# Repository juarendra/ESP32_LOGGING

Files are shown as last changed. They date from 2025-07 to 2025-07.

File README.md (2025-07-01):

# ESP32_LOGGING

## Table of Content

* [Product Specsification](#product-specsification)
* [Technical Spesification](#technical-spesification)
* [Applications](#applications)
* [Advantages](#advantages)
* [Priview Hardware](#priview-hardware)
* [Documentation](#documentation)
  * [Pinout Diagram](#pinout-diagram)
  * [Dimension](#dimension)
  * [BOM](#bom)
  * [Schematic](#schematic0)
  * [Example Program](#examples-program)
* [FAQ](#FAQ)

## Preview Hardware
<p align="center">
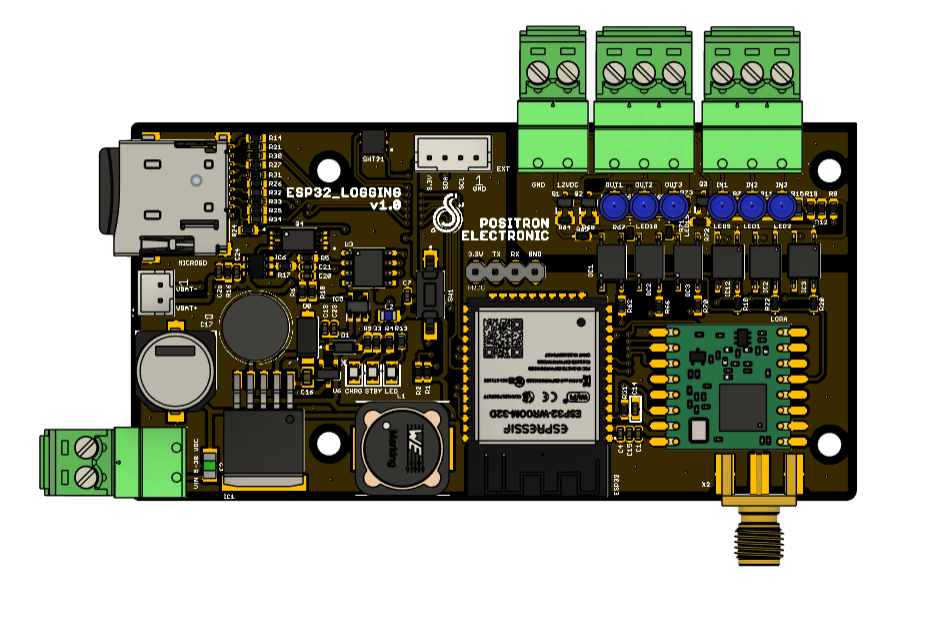
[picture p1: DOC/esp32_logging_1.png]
  
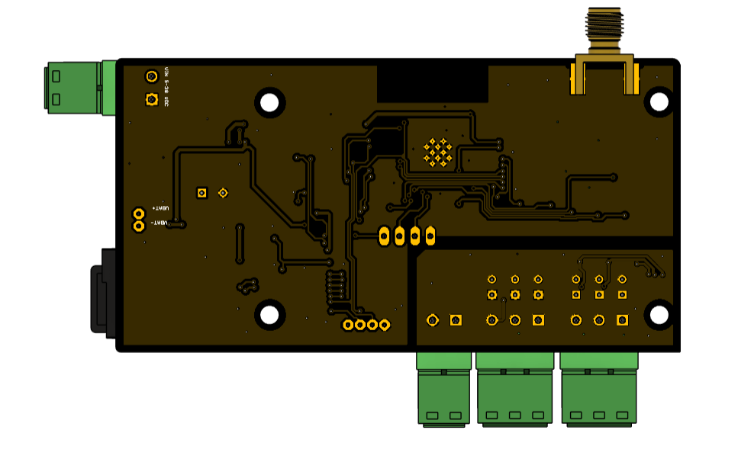
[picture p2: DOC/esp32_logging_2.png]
  
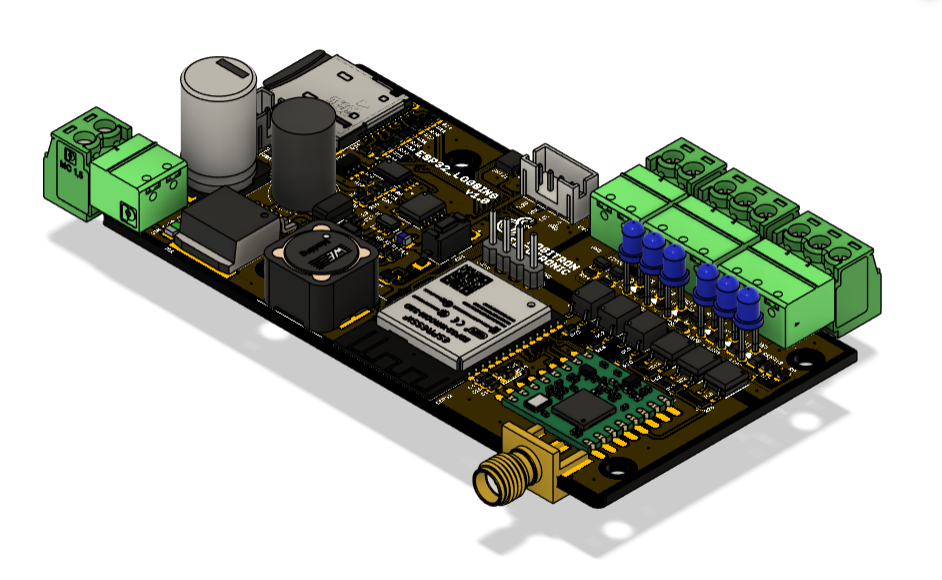
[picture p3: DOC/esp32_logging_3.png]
  
</p>

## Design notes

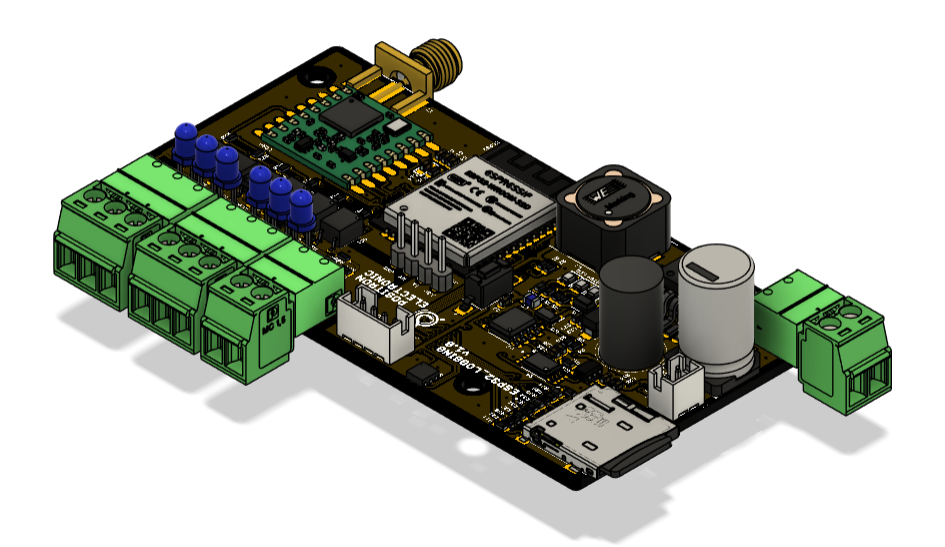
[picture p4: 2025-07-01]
DOC/esp32_logging_4.png

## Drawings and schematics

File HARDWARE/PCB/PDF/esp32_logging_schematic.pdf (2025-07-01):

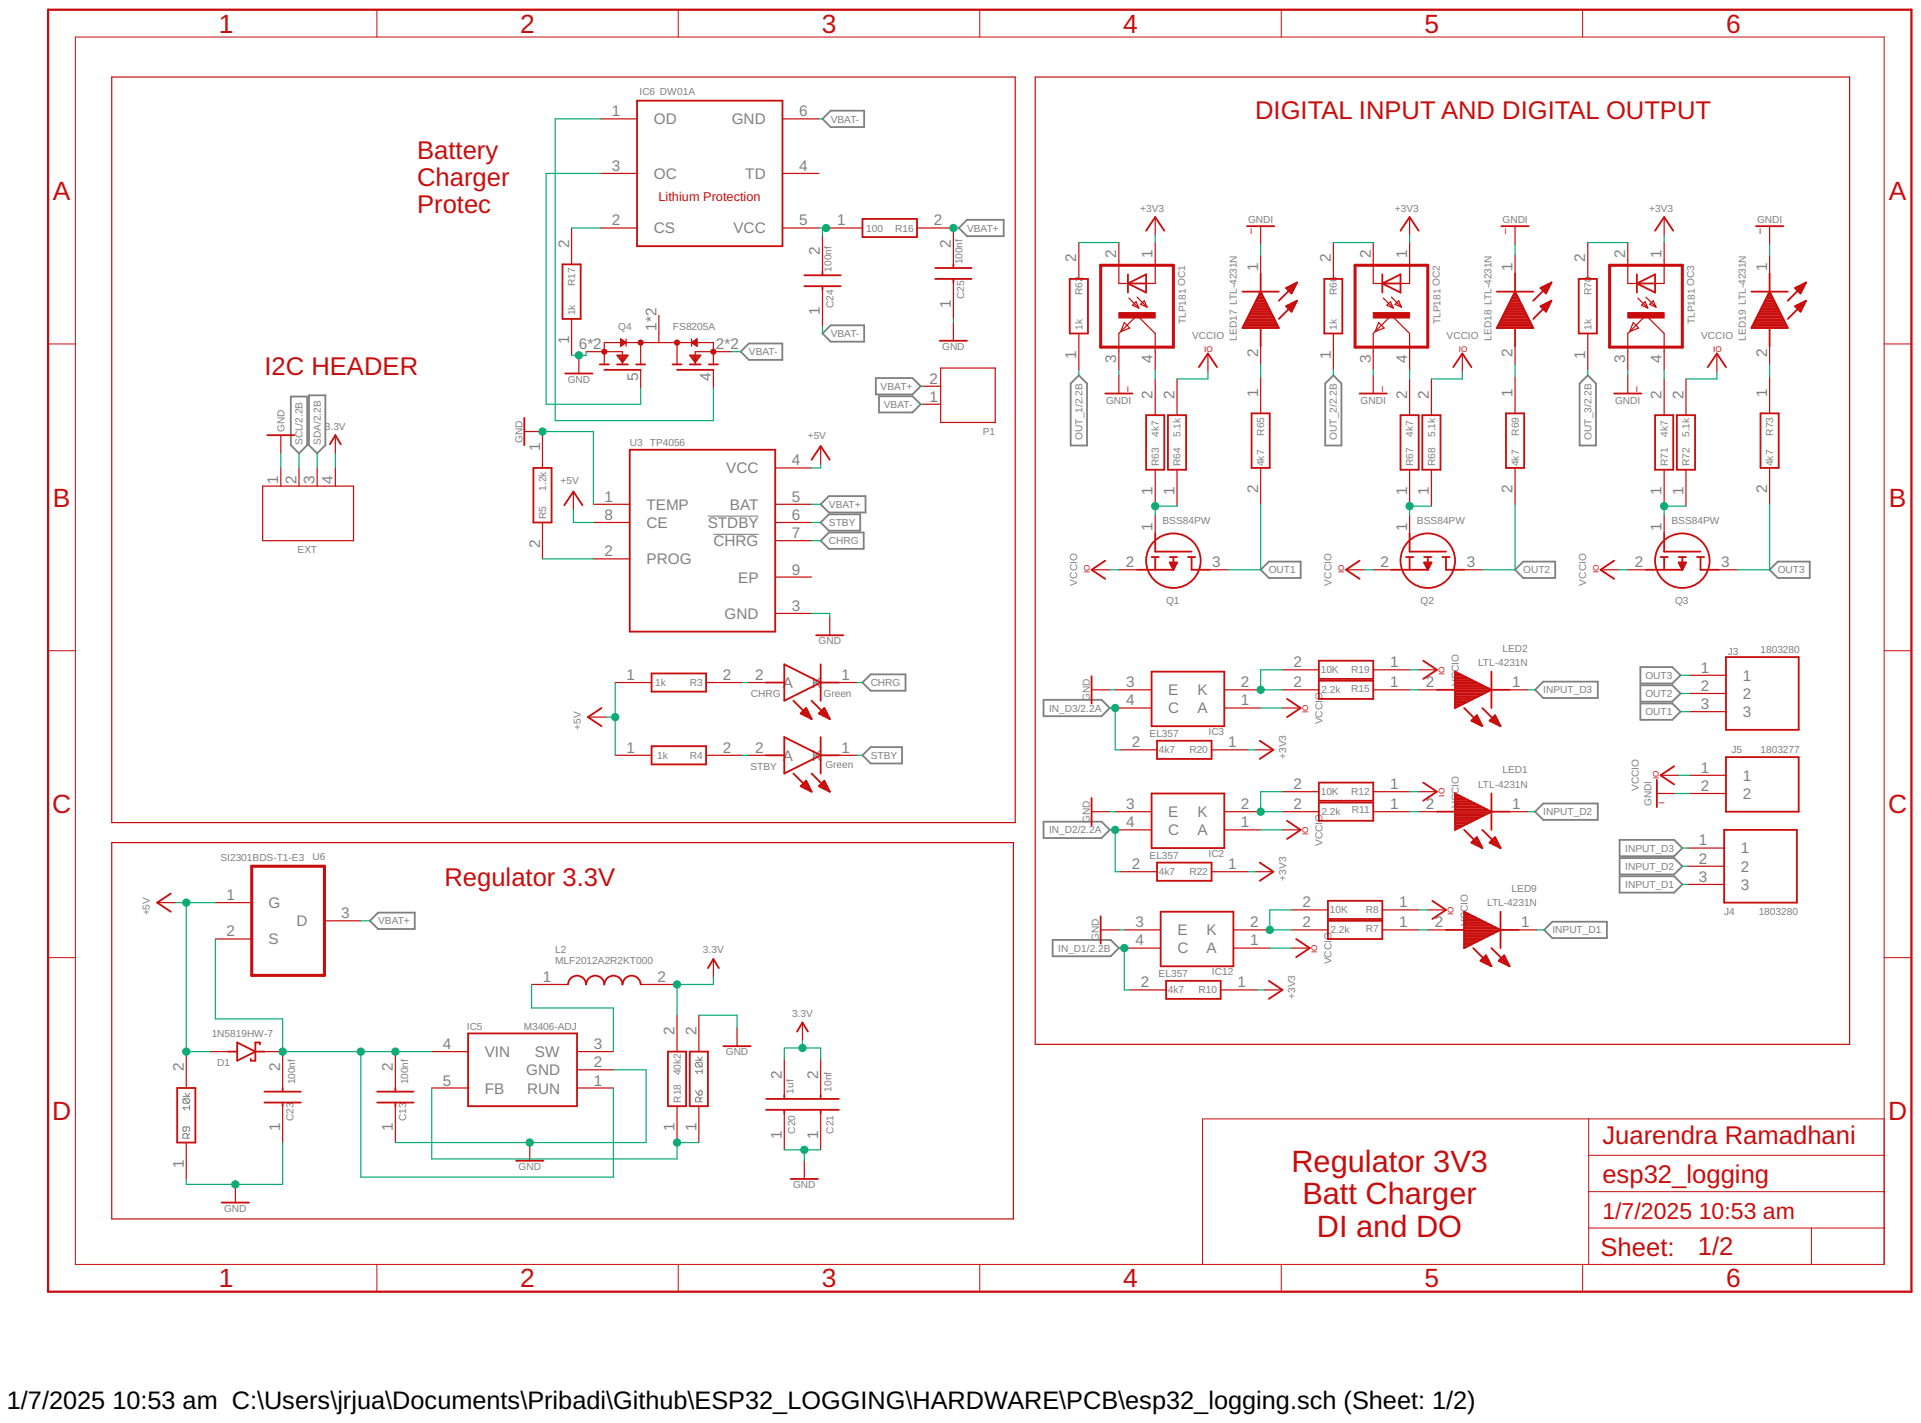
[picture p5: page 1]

DIGITAL INPUT AND DIGITAL OUTPUT

1/7/2025 10:53 am C:\Users\jrjua\Documents\Pribadi\Github\ESP32_LOGGING\HARDWARE\PCB\esp32_logging.sch (Sheet: 1/2)

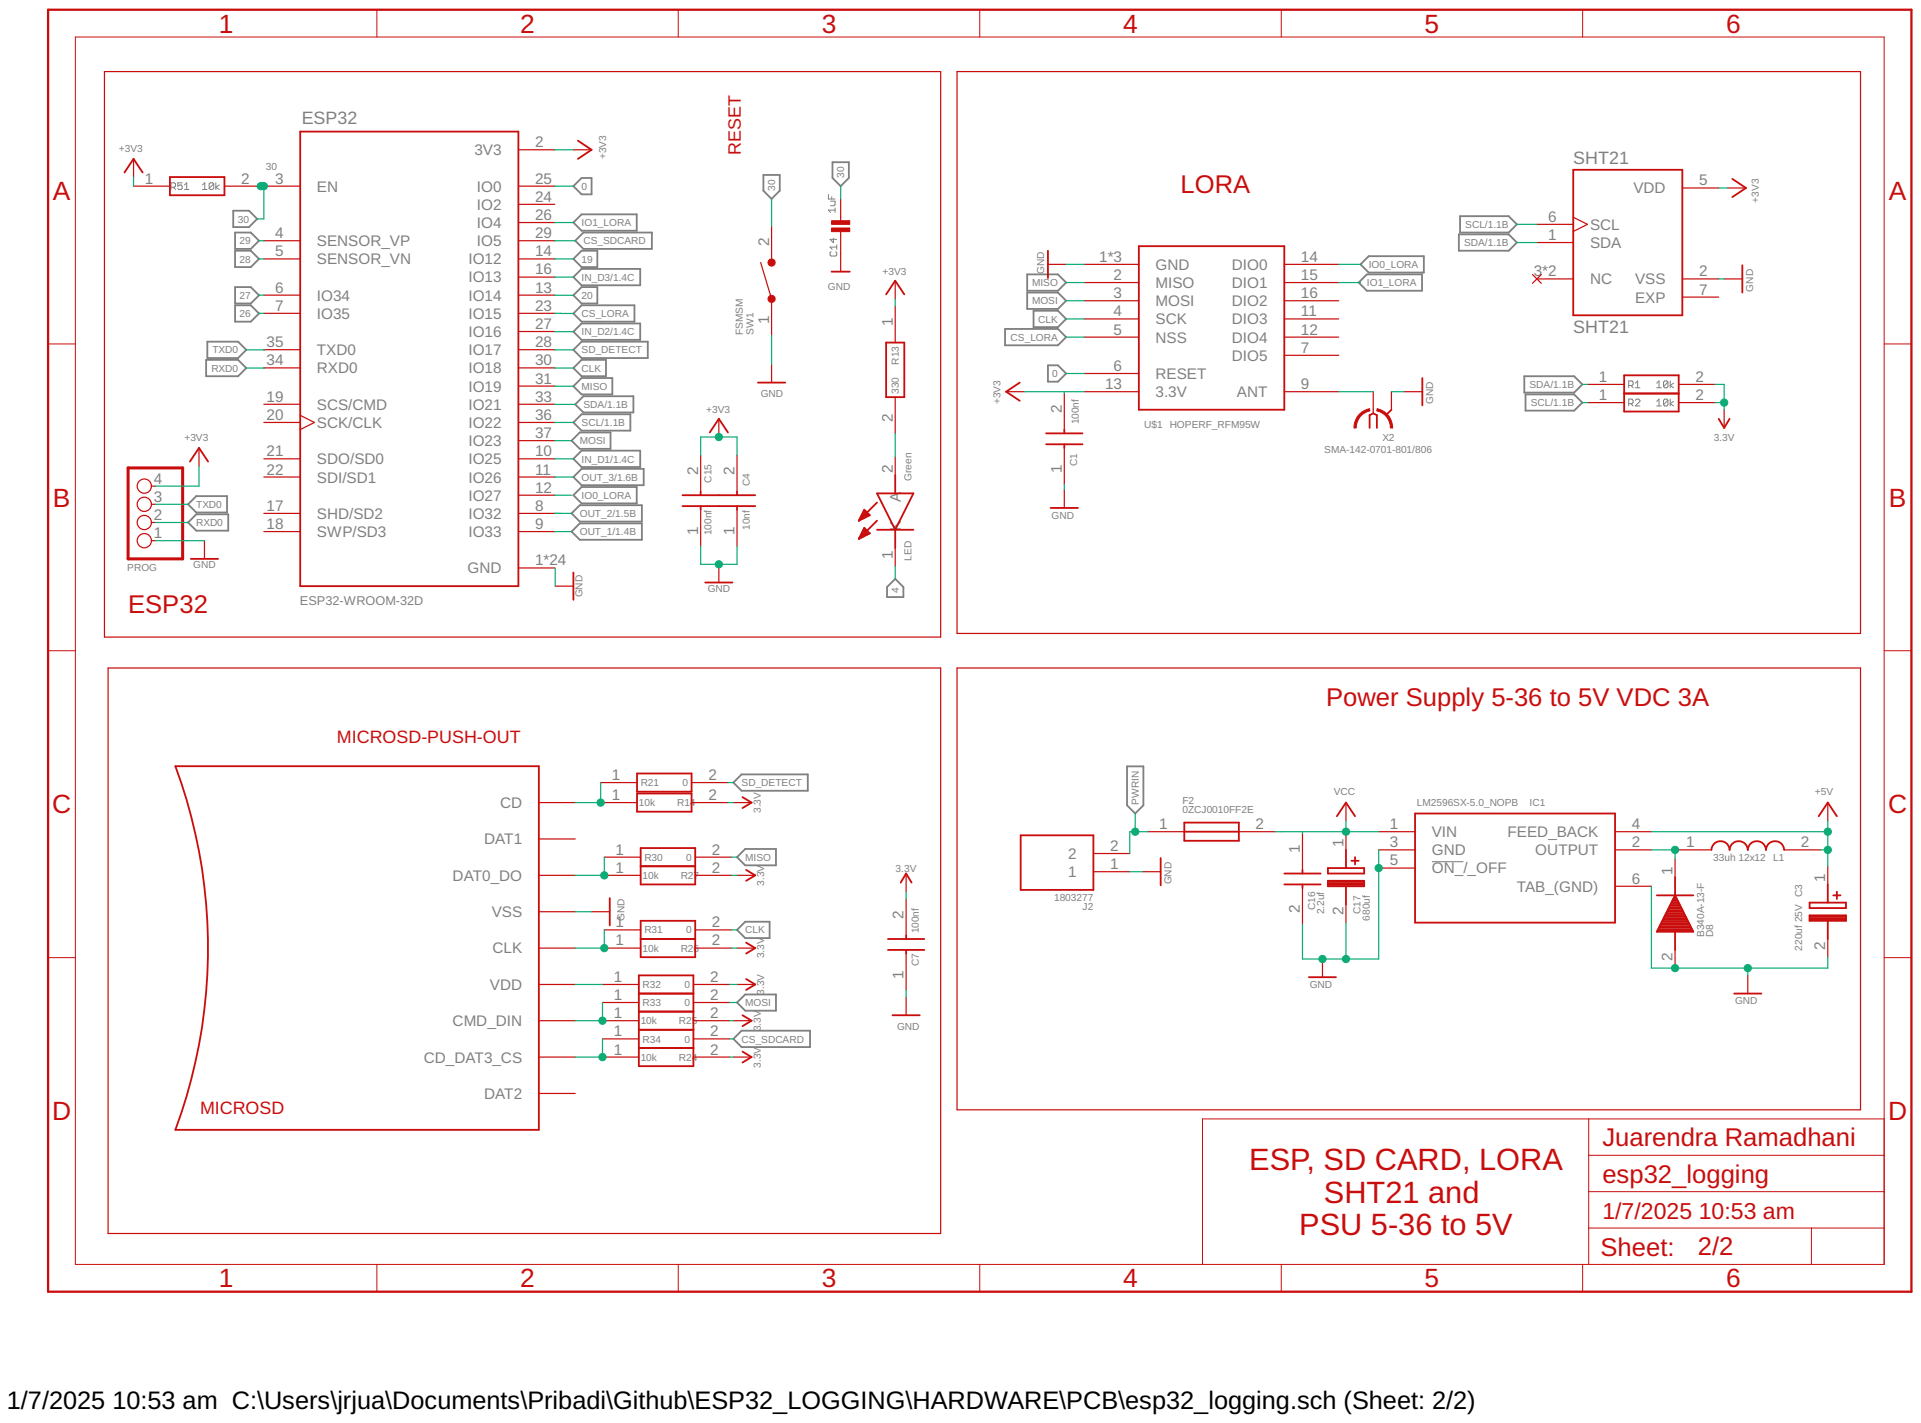
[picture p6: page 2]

Power Supply 5-36 to 5V VDC 3A

ESP, SD CARD, LORA
SHT21 and
PSU 5-36 to 5V

1/7/2025 10:53 am C:\Users\jrjua\Documents\Pribadi\Github\ESP32_LOGGING\HARDWARE\PCB\esp32_logging.sch (Sheet: 2/2)

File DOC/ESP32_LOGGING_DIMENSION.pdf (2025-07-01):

18.07

1.83

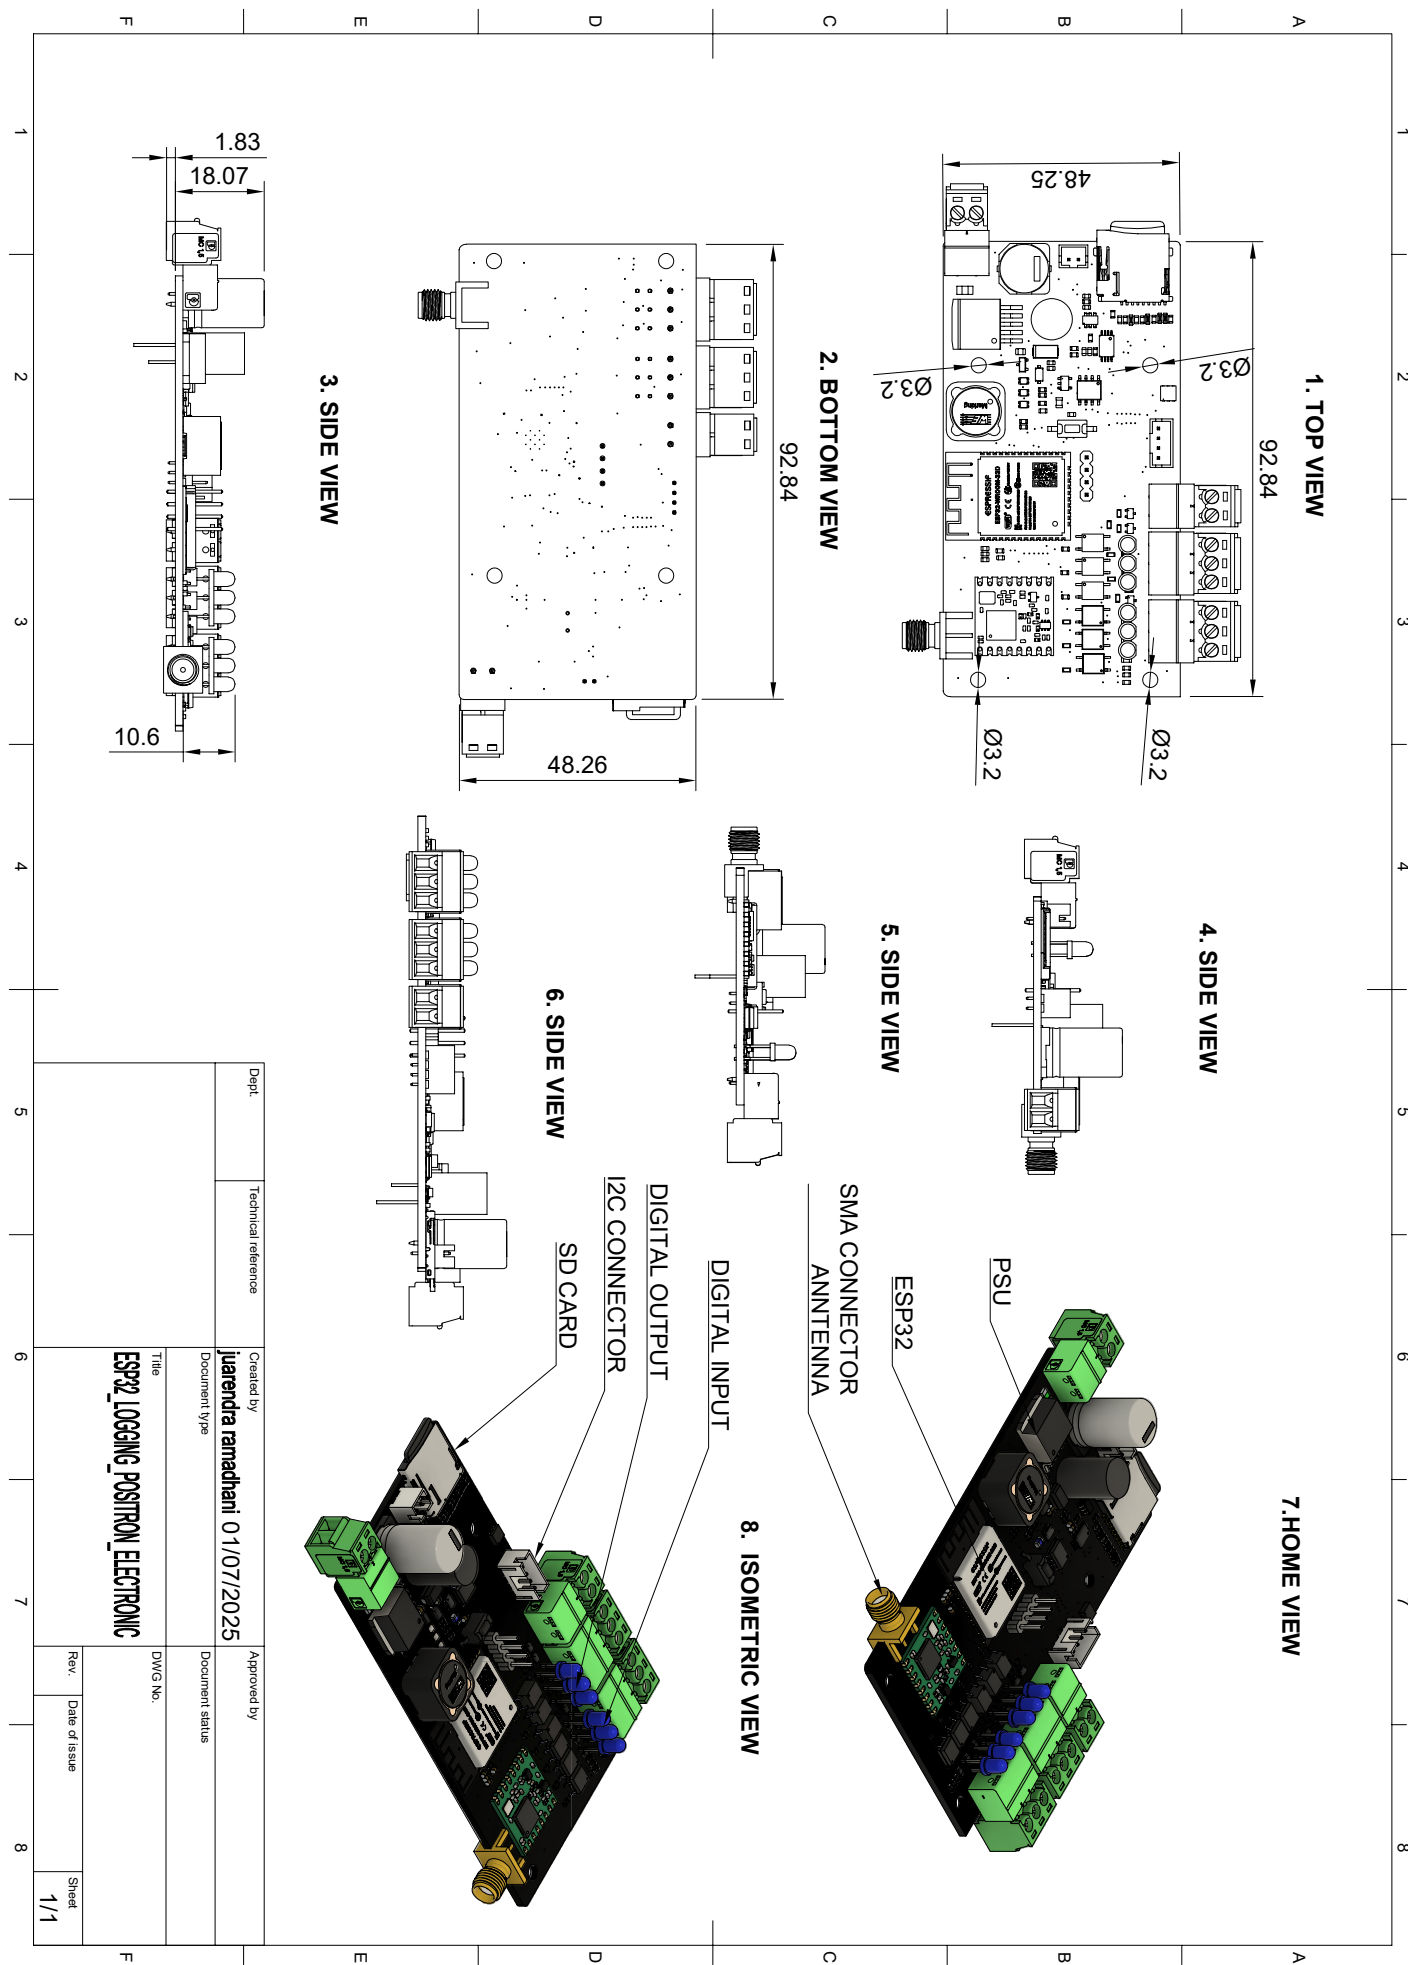
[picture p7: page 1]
PSUESP32 SMA CONNECTOR ANNTENNA SD CARD; DIGITAL OUTPUT; DIGITAL INPUT I2C CONNECTOR

1 A 2 3 4 5 6 7 8 1 2 3 4 5 6 7 8 FEDCB FEDCBA Dept. Technical reference Created by Approved by Title DWG No. Document type Document status Rev. Date of issue Sheet 01/07/2025 1/1 1. TOP VIEW 2. BOTTOM VIEW 3. SIDE VIEW 5. SIDE VIEW 4. SIDE VIEW 6. SIDE VIEW 7.HOME VIEW 8. ISOMETRIC VIEW

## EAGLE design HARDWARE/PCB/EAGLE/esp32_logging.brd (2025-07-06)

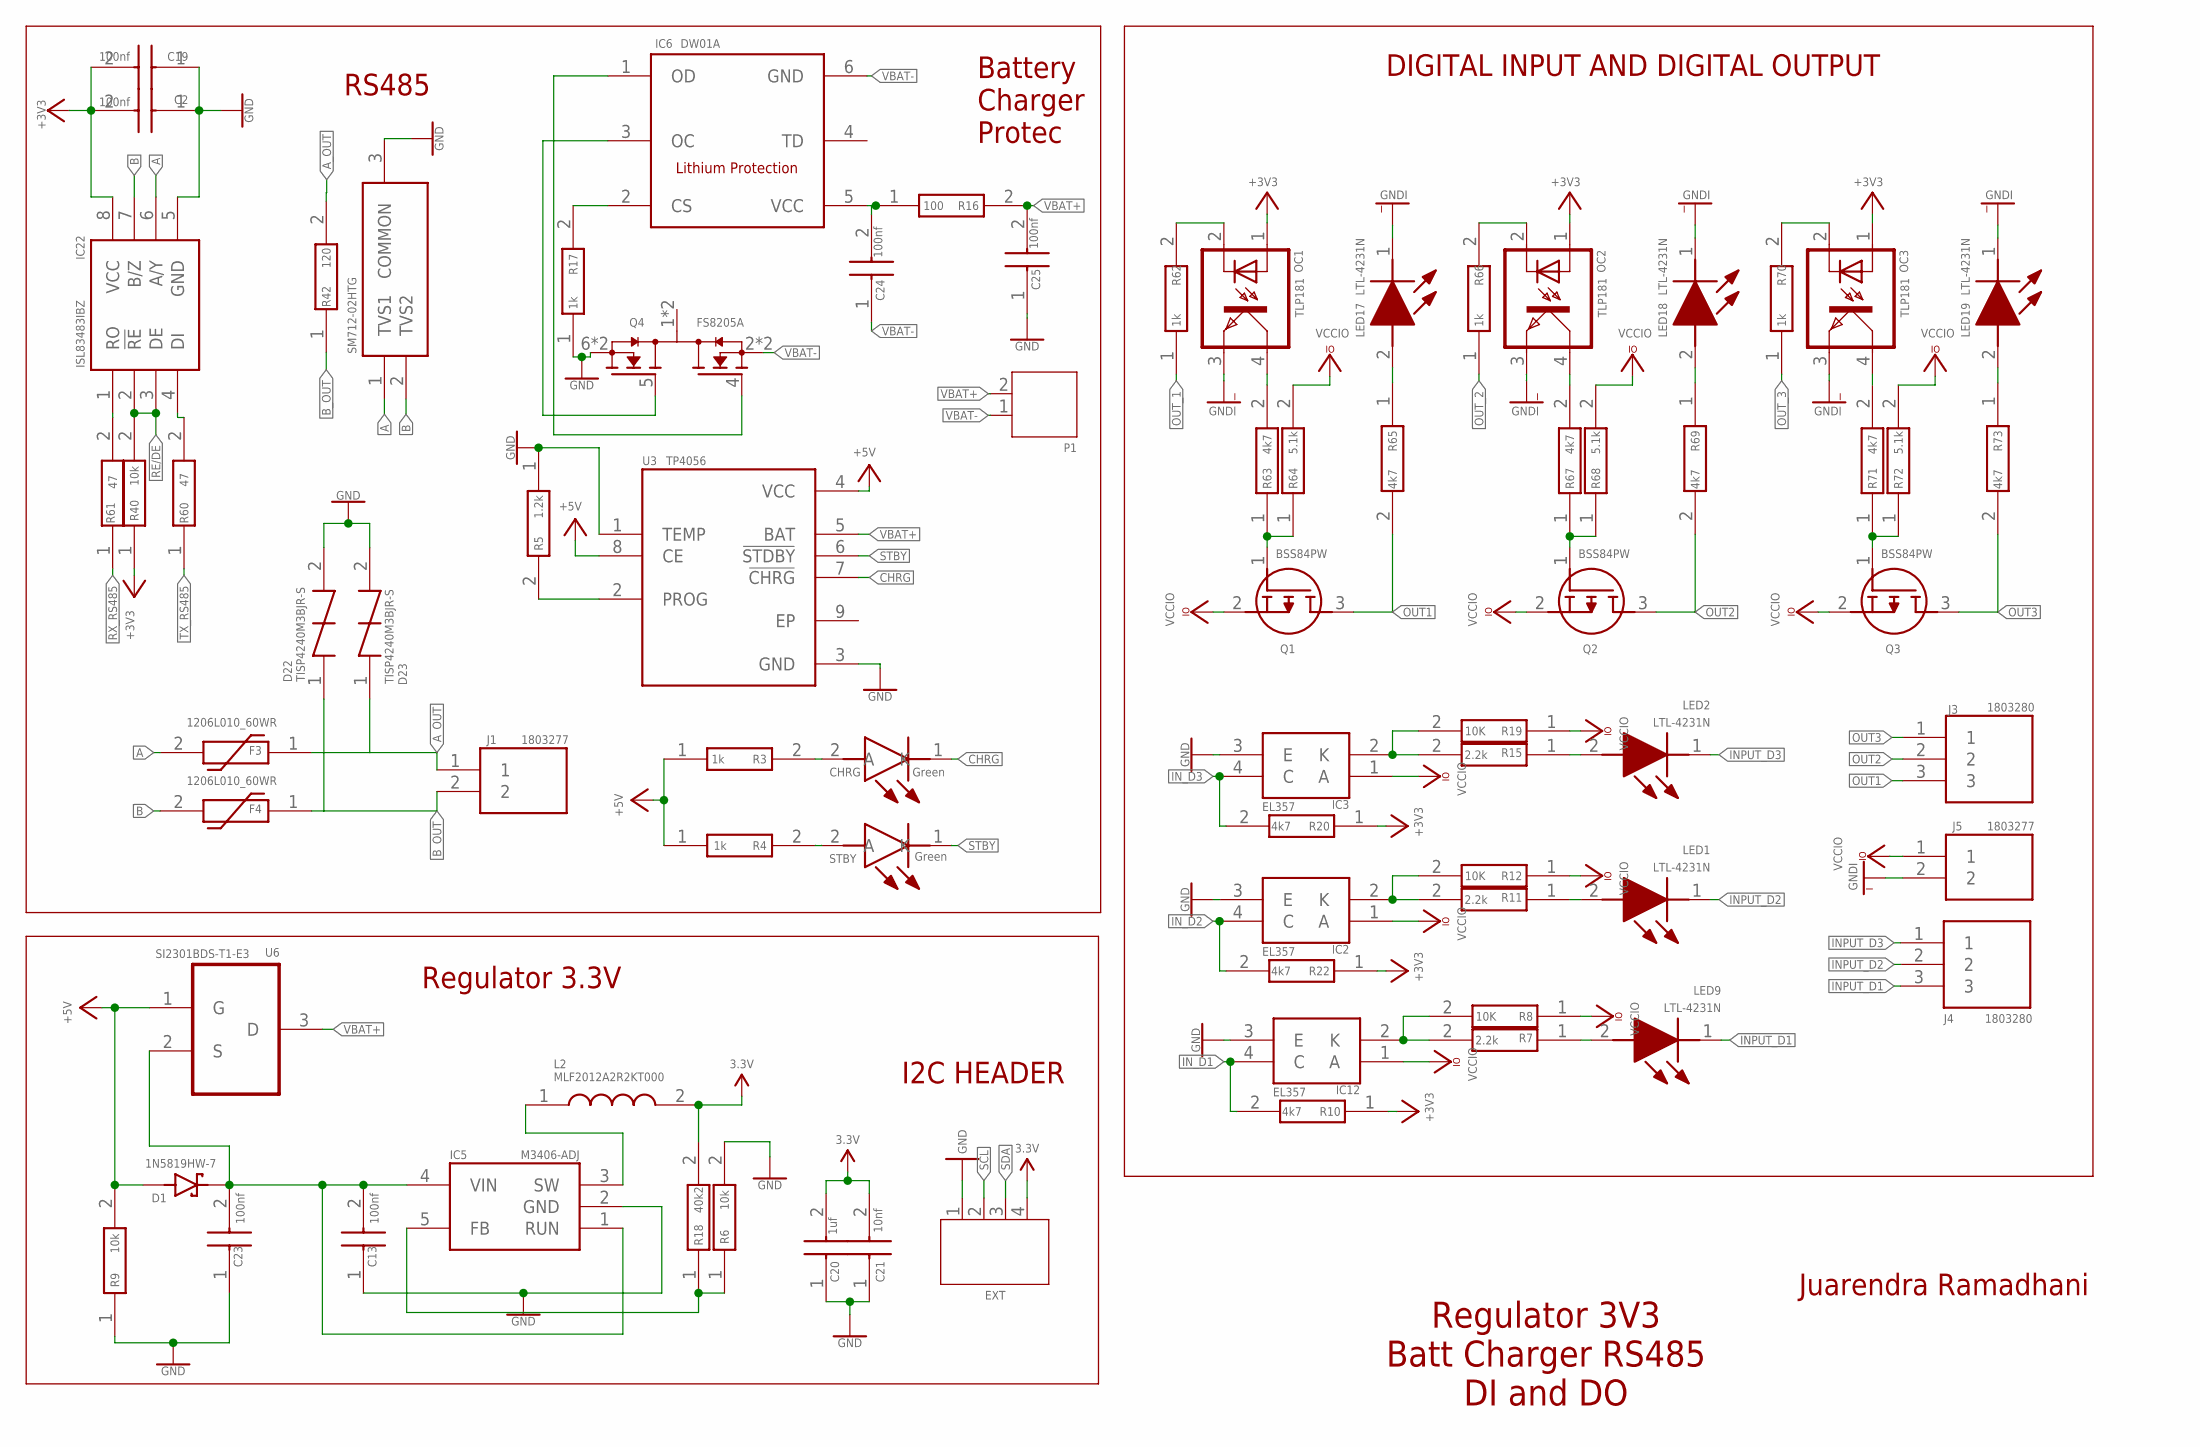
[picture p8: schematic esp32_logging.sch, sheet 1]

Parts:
C2, C13, C19, C23, C24, C25: 100nf; CAPC1608X87N
C20: 1uf; CAPC1608X87N
C21: 10nf; CAPC1608X87N
CHRG: Green; LEDC2012X80N
D1: 1N5819HW-7; SOD3715X145N
D6: SM712-02HTG; SOT95P237X111-3N
D22, D23: TISP4240M3BJR-S; TISP4240M3BJRS
EXT: JST-PH4
F3, F4: 1206L010_60WR; 1206L075132WR
IC2, IC3, IC12: EL357
IC5: M3406-ADJ; SOT95P280X100-5N
IC6: DW01A; SOT23-6
IC22: ISL83483IBZ; SOIC127P600X175-8N
J1, J5: 1803277
J3, J4: 1803280
L2: MLF2012A2R2KT000; INDC2012X105N
LED1, LED2, LED9, LED17, LED18, LED19: LTL-4231N; LTL4231N
OC1, OC2, OC3: TLP181; SO-4
P1: JST-PH2
Q1, Q2, Q3: BSS84PW; SOT65P210X100-3N
Q4: FS8205A; SOP65P640X120-8N
R3, R4, R17, R62, R66, R70: 1k; RESC1608X55N
R5: 1.2k; RESC1608X55N
R6, R9, R40: 10k; RESC1608X55N
R7, R11, R15: 2.2k; RESC2012X60N
R8, R12, R19: 10K; RESC1608X55N
R10, R20, R22, R63, R65, R67, R69, R71, R73: 4k7; ERA3AEB101V
R16: 100; RESC1608X55N
R18: 40k2; RESC1608X55N
R42: 120; RESC2012X65N
R60, R61: 47; RESC1608X55N
R64, R68, R72: 5.1k; RESC1608X55N
STBY: Green; LEDC2012X80N
U3: TP4056; SOP127P600X175-9N
U6: SI2301BDS-T1-E3; SOT95P237X112-3N

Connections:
3.3V: C2.2, C19.2, C20.2, C21.2, EXT.4, IC22.8 (VCC), L2.2, OC1.1 (A), OC2.1 (A), OC3.1 (A), R10.1, R18.2, R20.1, R22.1, R40.1; also elsewhere on the board
+5V: D1.A, R3.1, R4.1, R9.2, U3.4 (VCC), U3.8 (CE), U6.1 (G); also elsewhere on the board
A: D6.1 (TVS1), F3.2, IC22.6 (A/Y)
A_OUT: D23.1, F3.1, J1.1, R42.2
B: D6.2 (TVS2), F4.2, IC22.7 (B/Z)
B_OUT: D22.1, F4.1, J1.2, R42.1
CHRG: CHRG.1 (K), U3.7 (!CHRG)
GND: C2.1, C13.1, C19.1, C20.1, C21.1, C23.1, C25.1, D6.3 (COMMON), D22.2, D23.2, EXT.1, IC2.3 (E), IC3.3 (E), IC5.2 (GND), IC12.3 (E), IC22.5 (GND), Q4.6 (S2), Q4.7 (S2), R5.1, R6.2, R9.1, R17.1, U3.1 (TEMP), U3.3 (GND); also elsewhere on the board
GNDI: J5.2, LED17.1 (K), LED18.1 (K), LED19.1 (K), OC1.3 (EMIT), OC2.3 (EMIT), OC3.3 (EMIT)
INPUT_D1: J4.3, LED9.1 (K)
INPUT_D2: J4.2, LED1.1 (K)
INPUT_D3: J4.1, LED2.1 (K)
IN_D1: IC12.4 (C), R10.2; also elsewhere on the board
IN_D2: IC2.4 (C), R22.2; also elsewhere on the board
IN_D3: IC3.4 (C), R20.2; also elsewhere on the board
unnamed: C13.2, C23.2, D1.C (K), IC5.1 (RUN), IC5.4 (VIN), U6.2 (S)
unnamed: C24.2, IC6.5 (VCC), R16.1
unnamed: R4.2, STBY.2 (A)
unnamed: R5.2, U3.2 (PROG)
unnamed: IC6.1 (OD), Q4.4 (G1)
unnamed: IC5.3 (SW), L2.1
unnamed: IC2.2 (K), R11.2, R12.2
unnamed: IC12.2 (K), R7.2, R8.2
unnamed: CHRG.2 (A), R3.2
unnamed: LED1.2 (A), R11.1
unnamed: IC3.2 (K), R15.2, R19.2
unnamed: LED2.2 (A), R15.1
unnamed: OC1.4 (COL), R63.2
unnamed: IC6.2 (CS), R17.2
unnamed: IC5.5 (FB), R6.1, R18.1
unnamed: IC6.3 (OC), Q4.5 (G2)
unnamed: OC1.2 (C), R62.2
unnamed: Q1.1 (G), R63.1, R64.1
unnamed: OC2.4 (COL), R67.2
unnamed: LED17.2 (A), R65.1
unnamed: OC2.2 (C), R66.2
unnamed: Q2.1 (G), R67.1, R68.1
unnamed: LED18.2 (A), R69.1
unnamed: OC3.4 (COL), R71.2
unnamed: OC3.2 (C), R70.2
unnamed: Q3.1 (G), R71.1, R72.1
unnamed: LED19.2 (A), R73.1
unnamed: IC22.1 (RO), R61.2
unnamed: IC22.4 (DI), R60.2
unnamed: LED9.2 (A), R7.1
OUT1: J3.3, Q1.3 (D), R65.2
OUT2: J3.2, Q2.3 (D), R69.2
OUT3: J3.1, Q3.3 (D), R73.2
OUT_1: R62.1; also elsewhere on the board
OUT_2: R66.1; also elsewhere on the board
OUT_3: R70.1; also elsewhere on the board
RE/DE: IC22.2 (!RE), IC22.3 (DE), R40.2
RX_RS485: R61.1; also elsewhere on the board
SCL: EXT.2; also elsewhere on the board
SDA: EXT.3; also elsewhere on the board
STBY: STBY.1 (K), U3.6 (!STDBY)
TX_RS485: R60.1; also elsewhere on the board
VBAT+: C25.2, P1.2, R16.2, U3.5 (BAT), U6.3 (D)
VBAT-: C24.1, IC6.6 (GND), P1.1, Q4.2 (S1), Q4.3 (S1)
VCCIO: IC2.1 (A), IC3.1 (A), IC12.1 (A), J5.1, Q1.2 (S), Q2.2 (S), Q3.2 (S), R8.1, R12.1, R19.1, R64.2, R68.2, R72.2

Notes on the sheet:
Battery Charger Protec
Regulator 3.3V
I2C HEADER
Regulator 3V3 Batt Charger RS485 DI and DO
DIGITAL INPUT AND DIGITAL OUTPUT
Juarendra Ramadhani
RS485

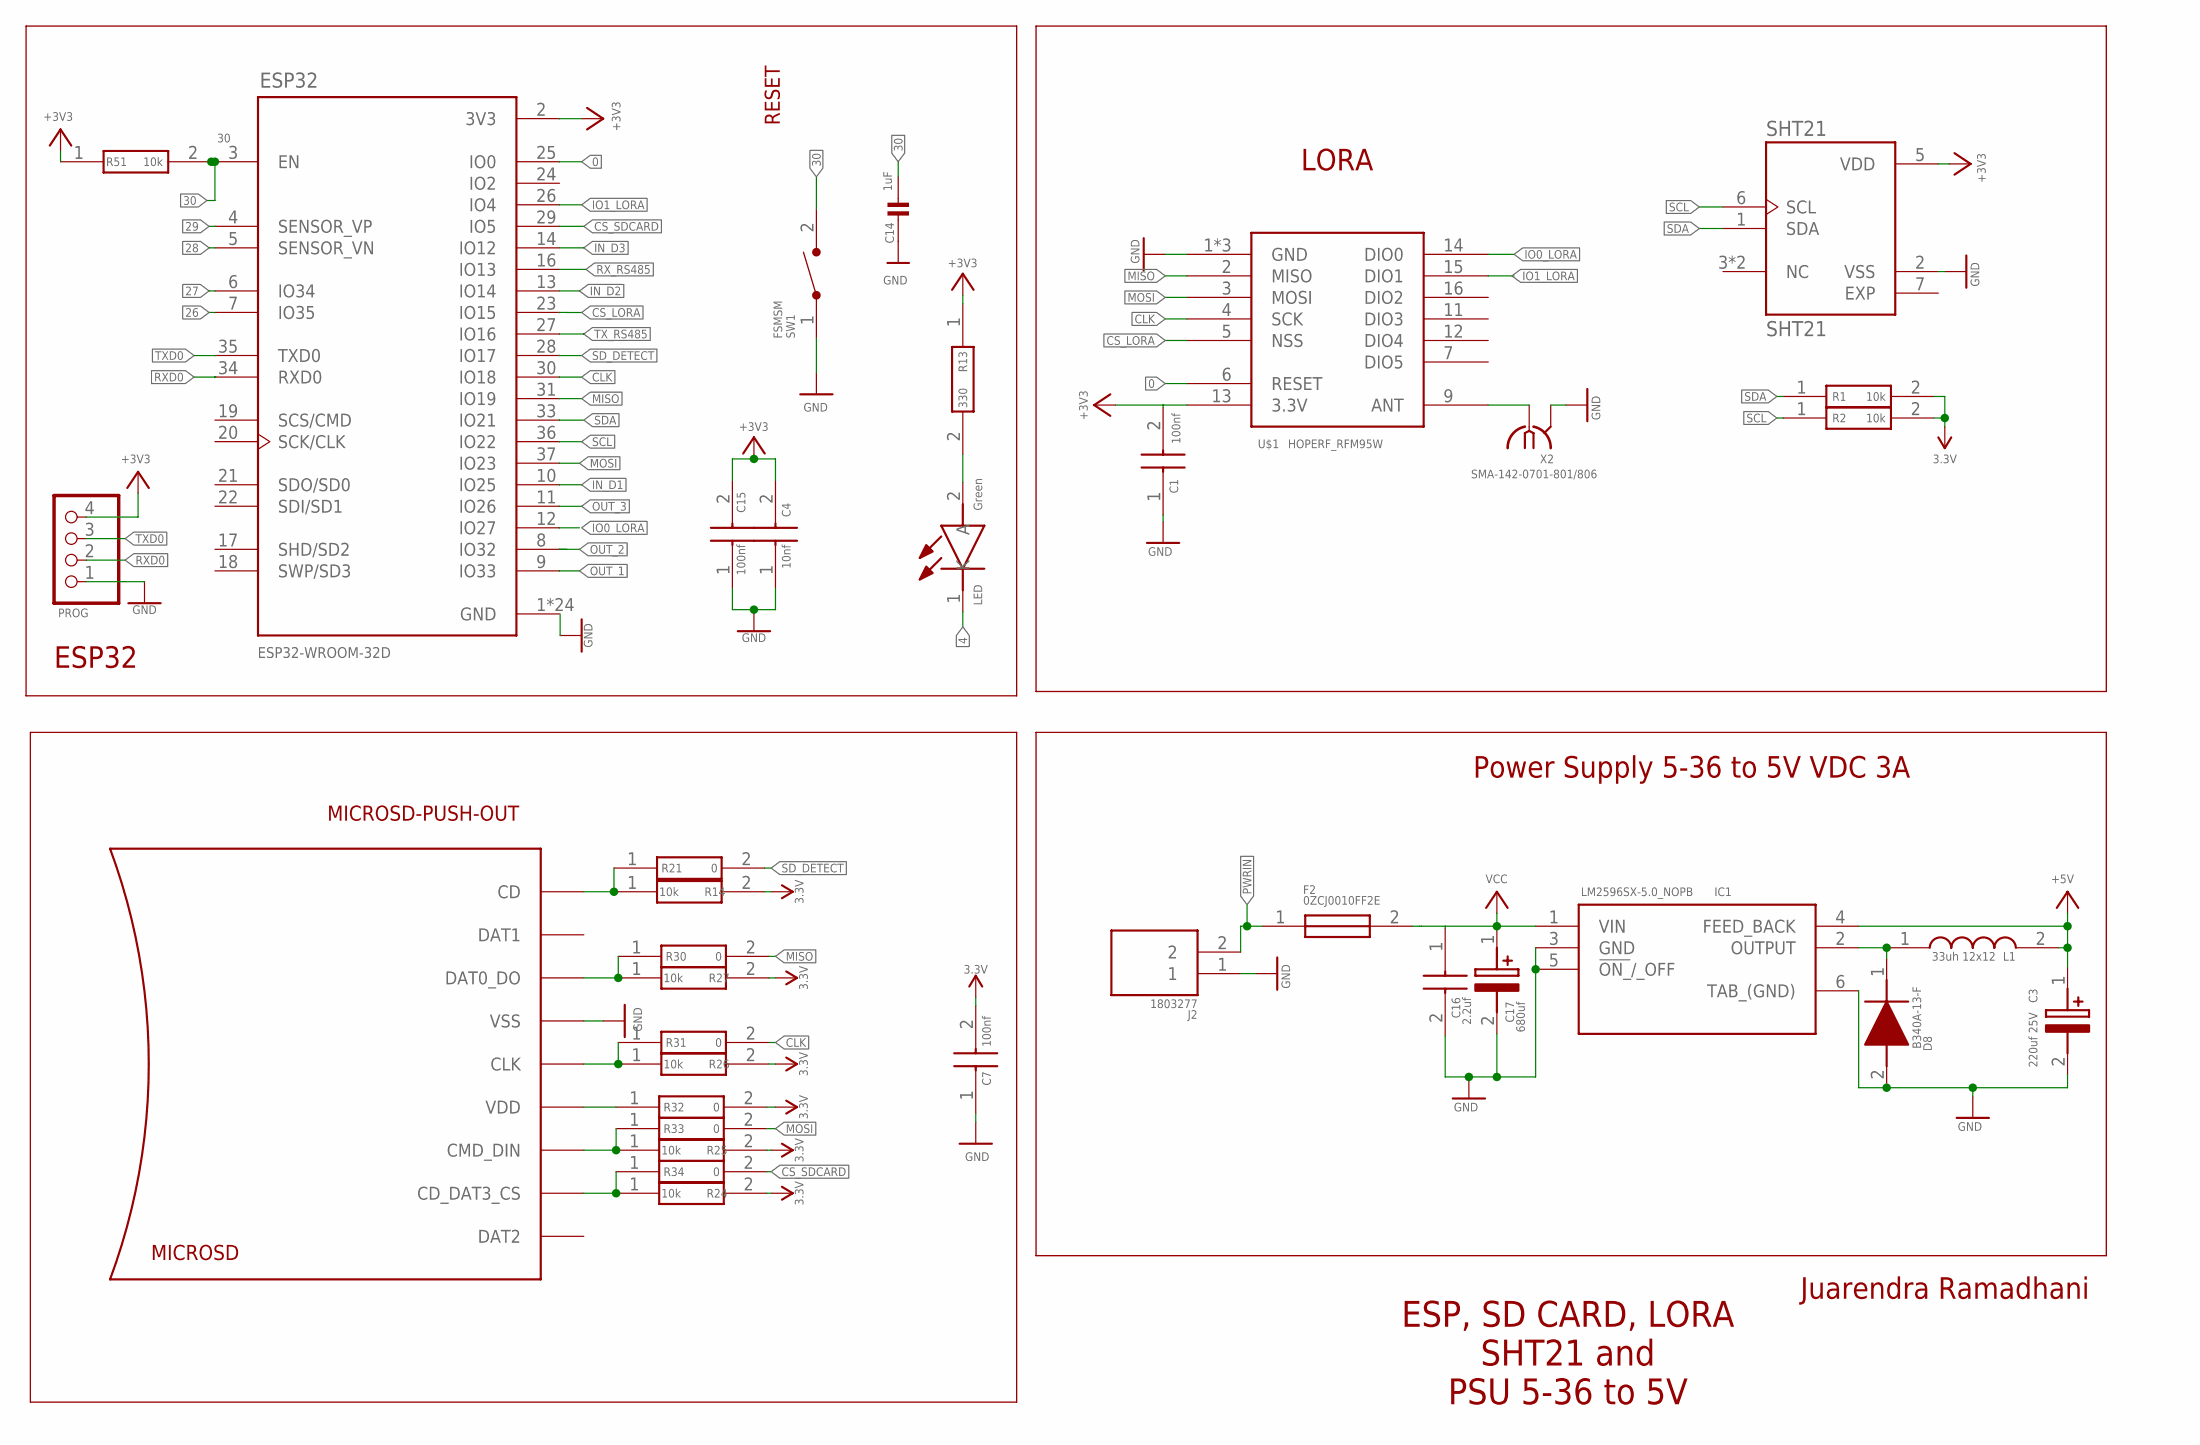
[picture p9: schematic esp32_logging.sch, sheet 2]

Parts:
C1, C7, C15: 100nf; CAPC1608X87N
C3: 220uf 25V; CAPPRD350W60D850H1250
C4: 10nf; CAPC1608X87N
C14: 1uF; 0603
C16: 2.2uf; CAPC2012X140N
C17: 680uf; EEHZS1H221P
D8: B340A-13-F; DIOM5226X240N
ESP32: ESP32-WROOM-32D; MODULE_ESP32-WROOM-32D
F2: 0ZCJ0010FF2E; FUSC3216X75N
IC1: LM2596SX-5.0_NOPB; KTT0005B
J2: 1803277
L1: 33uh 12x12; WE-PD_1260/1245/1280/121054
LED: Green; LEDC2012X80N
MICROSD: MICROSD-PUSH-OUT
PROG: PINHD-1X4; 1X04
R1, R2, R14, R24, R25, R26, R27, R51: 10k; RESC1608X55N
R13: 330; ERJH3
R21, R30, R31, R32, R33, R34: 0; RESC1608X55N
SHT21: SHT21; XDCR_SHT21
SW1: FSMSM
U$1: HOPERF_RFM95W
X2: SMA-142-0701-801/806; J502-ND-142-0701-801/806

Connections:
0: ESP32.25 (IO0), U$1.6 (RESET)
3.3V: C1.2, C4.2, C7.2, C15.2, ESP32.2 (3V3), PROG.4, R1.2, R2.2, R13.1, R14.2, R24.2, R25.2, R26.2, R27.2, R32.2, R51.1, SHT21.5 (VDD), U$1.13 (3.3V); also elsewhere on the board
4: LED.1 (K)
26: ESP32.7 (IO35)
27: ESP32.6 (IO34)
28: ESP32.5 (SENSOR_VN)
29: ESP32.4 (SENSOR_VP)
30: C14.1, ESP32.3 (EN), R51.2, SW1.2
+5V: C3.1 (+), IC1.4 (FEED_BACK), L1.2; also elsewhere on the board
CLK: ESP32.30 (IO18), R31.2, U$1.4 (SCK)
CS_LORA: ESP32.23 (IO15), U$1.5 (NSS)
CS_SDCARD: ESP32.29 (IO5), R34.2
GND: C1.1, C3.2 (-), C4.1, C7.1, C14.2, C15.1, C16.2, C17.2 (-), D8.2 (A), ESP32.1 (GND), ESP32.15 (GND), ESP32.38 (GND), ESP32.39_1 (GND), ESP32.39_2 (GND), ESP32.39_3 (GND), ESP32.39_4 (GND), ESP32.39_5 (GND), ESP32.39_6 (GND), ESP32.39_7 (GND), ESP32.39_8 (GND), ESP32.39_9 (GND), ESP32.39_10 (GND), ESP32.39_11 (GND), ESP32.39_12 (GND), ESP32.39_13 (GND), ESP32.39_14 (GND), ESP32.39_15 (GND), ESP32.39_16 (GND), ESP32.39_17 (GND), ESP32.39_18 (GND), ESP32.39_19 (GND), ESP32.39_20 (GND), ESP32.39_21 (GND), IC1.3 (GND), IC1.5 (!ON_!/_OFF), IC1.6 (TAB_(GND)), J2.1, MICROSD.6 (VSS), MICROSD.G1 (VSS), MICROSD.G2 (VSS), MICROSD.G3 (VSS), MICROSD.G4 (VSS), PROG.1, SHT21.2 (VSS), SW1.1, U$1.1 (GND), U$1.8 (GND), U$1.10 (GND), X2.G@1 (2), X2.G@2 (2), X2.G@3 (2), X2.G@4 (2); also elsewhere on the board
IN_D1: ESP32.10 (IO25); also elsewhere on the board
IN_D2: ESP32.13 (IO14); also elsewhere on the board
IN_D3: ESP32.14 (IO12); also elsewhere on the board
IO0_LORA: ESP32.12 (IO27), U$1.14 (DIO0)
IO1_LORA: ESP32.26 (IO4), U$1.15 (DIO1)
MISO: ESP32.31 (IO19), R30.2, U$1.2 (MISO)
MOSI: ESP32.37 (IO23), R33.2, U$1.3 (MOSI)
unnamed: MICROSD.CD, R14.1, R21.1
unnamed: MICROSD.7 (DAT0_DO), R27.1, R30.1
unnamed: U$1.9 (ANT), X2.1
unnamed: MICROSD.5 (CLK), R26.1, R31.1
unnamed: MICROSD.3 (CMD_DIN), R25.1, R33.1
unnamed: MICROSD.2 (CD_DAT3_CS), R24.1, R34.1
unnamed: D8.1 (K), IC1.2 (OUTPUT), L1.1
unnamed: MICROSD.4 (VDD), R32.1
unnamed: LED.2 (A), R13.2
OUT_1: ESP32.9 (IO33); also elsewhere on the board
OUT_2: ESP32.8 (IO32); also elsewhere on the board
OUT_3: ESP32.11 (IO26); also elsewhere on the board
PWRIN: F2.1, J2.2
RXD0: ESP32.34 (RXD0), PROG.2
RX_RS485: ESP32.16 (IO13); also elsewhere on the board
SCL: ESP32.36 (IO22), R2.1, SHT21.6 (SCL); also elsewhere on the board
SDA: ESP32.33 (IO21), R1.1, SHT21.1 (SDA); also elsewhere on the board
SD_DETECT: ESP32.28 (IO17), R21.2
TXD0: ESP32.35 (TXD0), PROG.3
TX_RS485: ESP32.27 (IO16); also elsewhere on the board
VCC: C16.1, C17.1 (+), F2.2, IC1.1 (VIN)

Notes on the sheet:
RESET
ESP32
ESP, SD CARD, LORA SHT21 and PSU 5-36 to 5V
Power Supply 5-36 to 5V VDC 3A
LORA
Juarendra Ramadhani

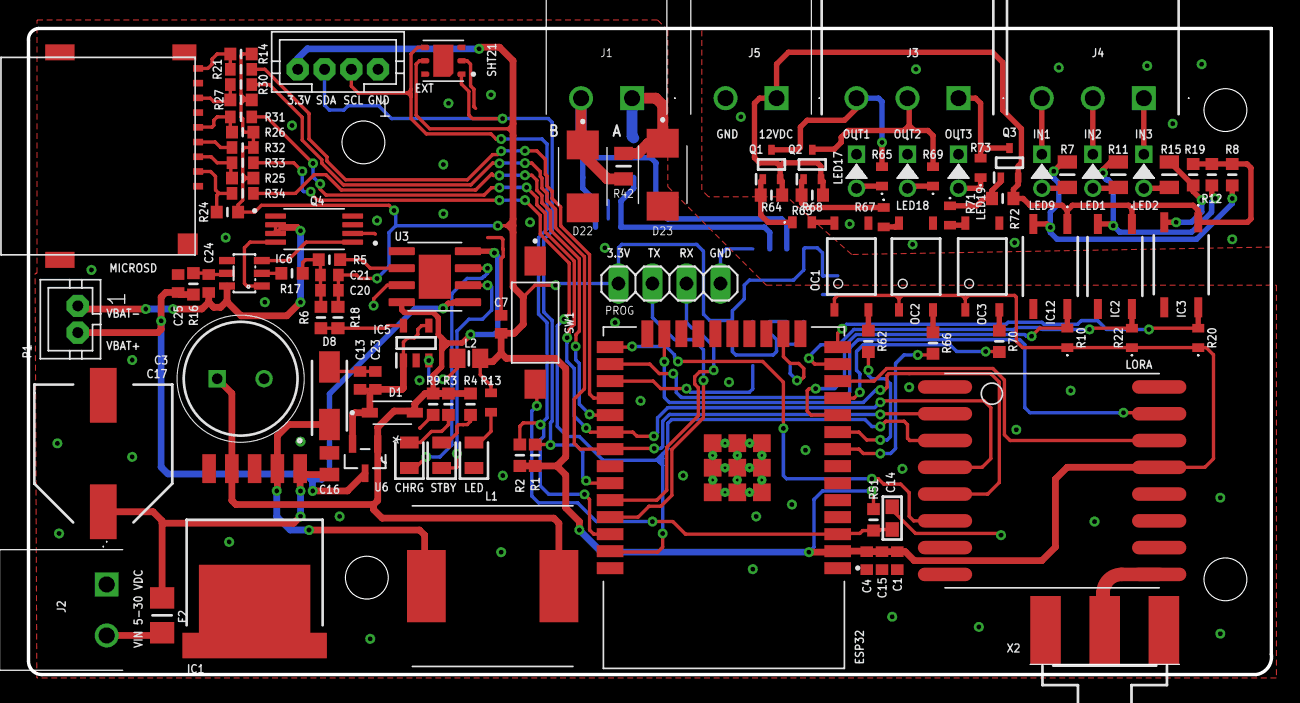
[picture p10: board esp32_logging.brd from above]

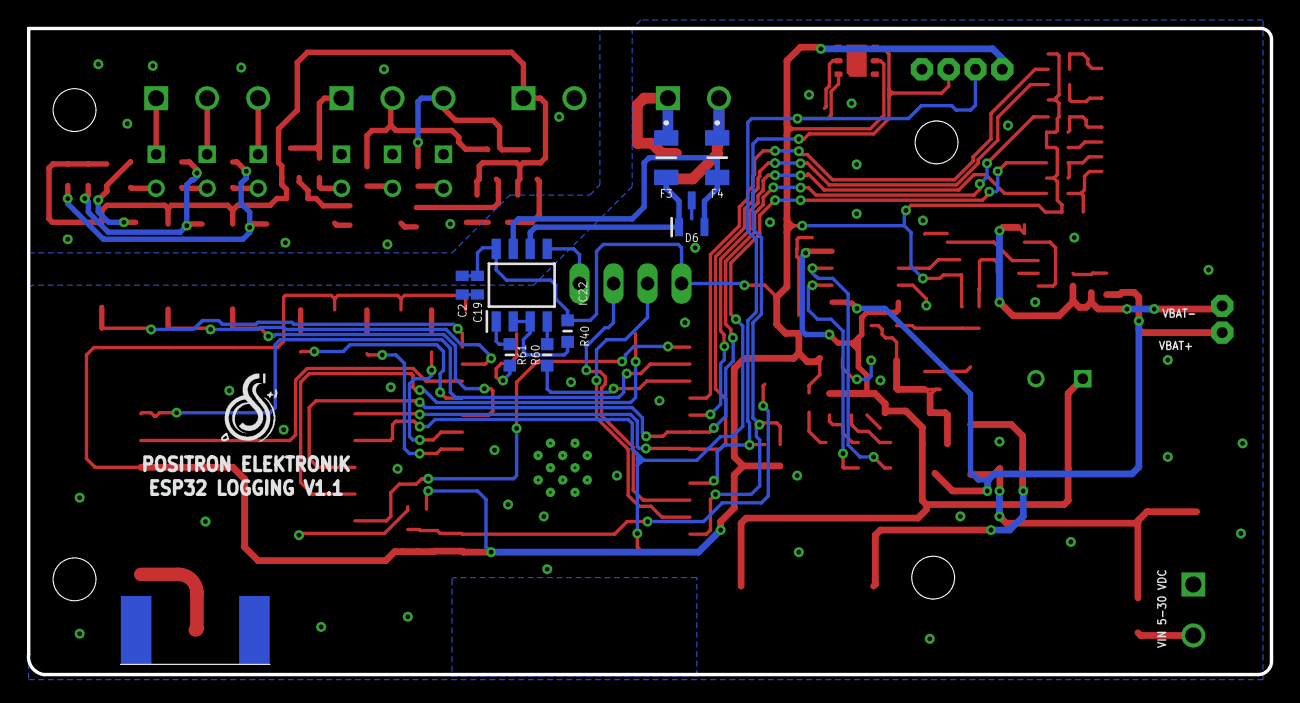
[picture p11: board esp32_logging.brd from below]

Board: 2 copper layers, 92.9 x 48.3 mm, 113 parts (9 on the bottom side), 83 nets.

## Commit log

2025-06-30 FEAT : add first design pcb
    [esp32_logging.brd, esp32_logging.sch]
2025-07-01 FEAT : update pcb and documentation file
    [esp32_logging.brd, esp32_logging.sch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]
2025-07-06 FEAT: add rs485 line
    [esp32_logging.brd, esp32_logging.sch]

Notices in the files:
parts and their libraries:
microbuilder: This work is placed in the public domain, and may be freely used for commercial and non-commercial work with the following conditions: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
